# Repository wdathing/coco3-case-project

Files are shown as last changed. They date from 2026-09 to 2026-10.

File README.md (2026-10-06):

# CoCo3 Streamline Case

A parametric, 3D-printable replacement case for the Tandy Color Computer 3 (26-3334 motherboard), styled after
the never-released "CoCo4" prototype: a low keyboard deck in front of a taller louvered tower that houses the
motherboard and two 3.5" drive bays.

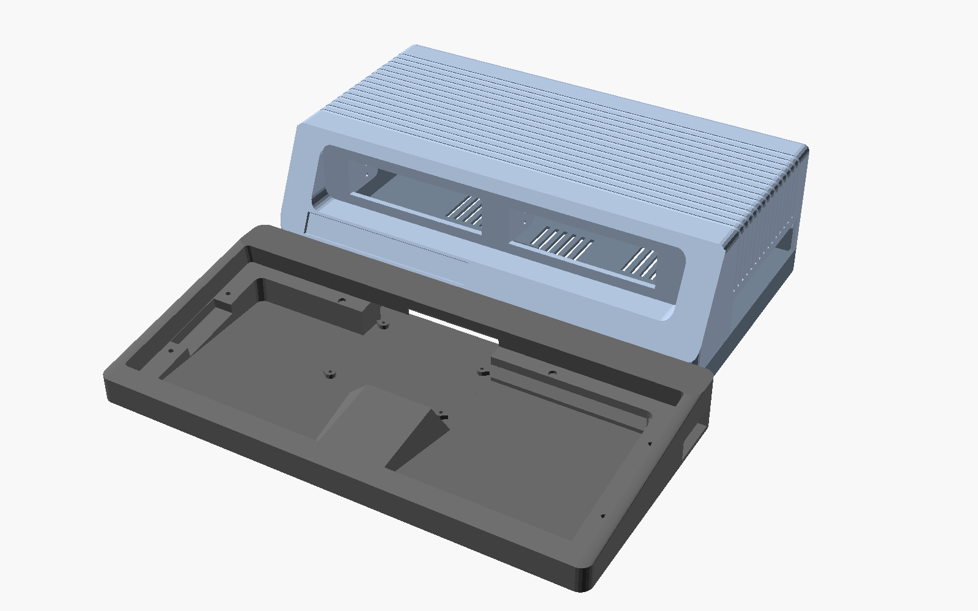
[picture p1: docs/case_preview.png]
The case: main tower and detachable keyboard shell


Everything is generated from OpenSCAD source ([`coco3_case.scad`](coco3_case.scad)). The motherboard outline,
mounting holes and connector positions come from a KiCad STEP model of the real board, so the rear ports and the
right-side cartridge slot line up with a stock CoCo3 board.

## Features

- **Fits a 250 x 250 mm bed.** The main case and keyboard shell are split into left/right halves, joined with M3
  screws, nuts and printed pins. "Whole" versions of each part are included for bigger printers.
- **Multipak-compatible cartridge slot.** The motherboard sits at the stock height above the desk, so a Multipak
  or a cartridge plugs into the right-side slot as it would on a stock case.
- **Keyboard shell** for either the original CoCo3 keyboard or an Artemis v3 replacement keyboard, each with its
  own bezel. The shell attaches with magnets (detachable) or bolts (permanent).
- **Two 3.5" drive bays** in the tower for floppy or Gotek drives, with filler plates for empty bays and a tray
  that holds a CoCo FujiNet board and its OLED display in a bay.
- **Modern I/O:** USB-C power input that replaces the OEM power connector, USB passthrough faceplates for a Pico-based
  USB keyboard controller, a rear panel for an HDMI/video add-on board, and mounting for a Raspberry Pi Zero
  (RGBtoHDMI) or an HDMI bulkhead coupler.
- **Build variants:**
  - **One-piece bottom.** The main bottom and keyboard shell print as a single part, for large printers
    (~334 x 341 mm footprint).
  - **Hinged lid.** The rear wall becomes part of the bottom and the top swings up on a 3 mm rod for access to the
    drives and motherboard.

## Which files to print

Ready-to-print STLs are in [`stl/`](stl) (the standard case) and [`hinged-stls/`](hinged-stls) (hinged-lid
versions of the main case parts). Pick one row from each group that applies:

| Part | Fits 250 mm bed (split) | Bigger printer (whole) |
|---|---|---|
| Main case bottom | `main_bottom_left` + `main_bottom_right` | `main_bottom_whole` |
| Main case top | `main_top_left` + `main_top_right` | `main_top_whole` |
| Keyboard shell | `keyboard_bottom_left` + `keyboard_bottom_right` + `keyboard_joiner_keys` | `keyboard_bottom_whole` |
| Keyboard bezel, stock keyboard | `bezel_oem_left` + `bezel_oem_right` | `bezel_oem_whole` |
| Keyboard bezel, Artemis v3 | `bezel_artemis_left` + `bezel_artemis_right` | `bezel_artemis_whole` |

Plus:

- `main_faceplate` and `keyboard_faceplate`: the USB/LED/button plates for the main case front and the keyboard's
  back wall.
- `keyboard_main_keys`: bow-tie keys that join the keyboard shell to the main bottom underneath.
- `keyboard_magnet_plugs` (detachable keyboard) **or** `keyboard_bridge_plate` (permanently attached keyboard).
- `usbc_clip`: holds the USB-C power board.
- Optional: `fujinet_tray`, `floppy_filler_plate` + 2x `floppy_filler_clip` (per empty bay).

**One-piece bottom (large printers):** print `bottom_one_piece` in place of the main bottom and keyboard shell
(and their keys/plugs), with `main_top_whole_1p` as the top. Its skirt is 5 mm taller to match.

**Hinged lid:** use the main case parts (`main_bottom_*`, `main_top_*`, `main_faceplate`, `bottom_one_piece`,
`main_top_whole_1p`) from `hinged-stls/`; everything else still comes from `stl/`.

## Hardware

- M3 screws throughout. By default they self-tap into 2.6 mm pilot holes; set `screw_mount_type = "heat_set"` for
  brass heat-set inserts (4.0 mm holes) instead.
- M3 x 10 (or x 12) socket-head screws and M3 nuts for the seams between split halves. Bolt the main case halves
  together *before* fitting the drives.
- 6 x 3 mm disc magnets for the detachable keyboard.
- 5 mm stick-on rubber feet.
- Hinged lid only: a 3 mm steel rod, about 306 mm long, glued at the ends.

## Building the STLs yourself

The STLs are generated from the `.scad` files by a build script. It needs an
[OpenSCAD development snapshot](https://openscad.org/downloads.html#snapshots) (2024 or later): the scripts use
the Manifold backend, which renders the whole set in seconds. The 2021.01 stable release doesn't have it.

```sh
./build_stls.sh                  # Linux / macOS: everything
./build_stls.sh hinged-stls      # just one folder
./build_stls.sh main_top_left    # just one part (in every folder that has it)
```

```bat
build_stls.cmd                   :: Windows, same arguments (or .\build_stls.ps1 from PowerShell)
```

The scripts find OpenSCAD on the `PATH` or in its default install location; set `OPENSCAD` to point at a specific
binary. The list of parts, with the settings each one is built with, is in [`stl_parts.txt`](stl_parts.txt).

## Customizing

Open `coco3_case.scad` in OpenSCAD and use the Customizer, or edit the variables at the top of the file. The most
useful ones:

| Variable | What it does |
|---|---|
| `part` | Which part to render. `"preview"` shows the case assembled; the full list is in the PART SELECTOR block at the end of the file. |
| `keyboard_attached` | `false` = detachable keyboard (magnets), `true` = bolted on. |
| `one_piece_bottom` | Fuse the main bottom and keyboard shell into one print. |
| `main_hinged` | Hinged-lid build. |
| `screw_mount_type` | `"self_tap"` or `"heat_set"`. |
| `new_foot_height` | Height of your stick-on feet. The standoffs adjust to keep the cartridge slot at Multipak height. |
| `tol` | General fit clearance. |

The floppy filler plate lives in its own file, [`coco3_floppy_filler.scad`](coco3_floppy_filler.scad).

## Status

This is a hobby project. Parts have been test-printed and fitted as the design evolved, but not every variant
has been printed. Check fit on your own printer before committing to a long print. A few dimensions are best
estimates, such as the height of the OEM rubber feet that the cartridge-height calculation starts from. They are
marked `PLACEHOLDER` / `TODO` in the source.

## Third-party files

These reference files are included for convenience and are **not** covered by this project's license. They
remain under their original owners' terms:

- `coco3.step`: CoCo3 motherboard model, from
  [qbancoffee/coco_motherboards](https://github.com/qbancoffee/coco_motherboards) (GPL-3.0).
- `coco4_reference.jpg`: photo of the CoCo4 prototype, used as the styling reference.
- `Artemis v3 bezel.stl`: bezel model for the Artemis v3 keyboard.
- `CoCo-FujiNet-Rev000.stl`: model of the CoCo FujiNet board.

## License

Copyright (c) 2026 Bill Athing.

Licensed under [Creative Commons Attribution 4.0 International (CC BY 4.0)](LICENSE). You can share, remix and
sell prints or derivatives, as long as you give credit, e.g. *"CoCo3 Streamline Case" by Bill Athing,
https://github.com/wdathing/coco3-case-project*, and note any changes you made.

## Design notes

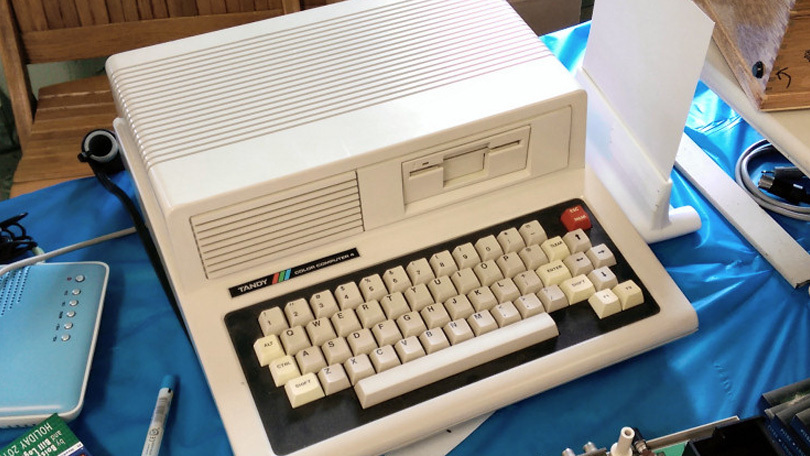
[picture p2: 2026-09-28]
coco4_reference.jpg

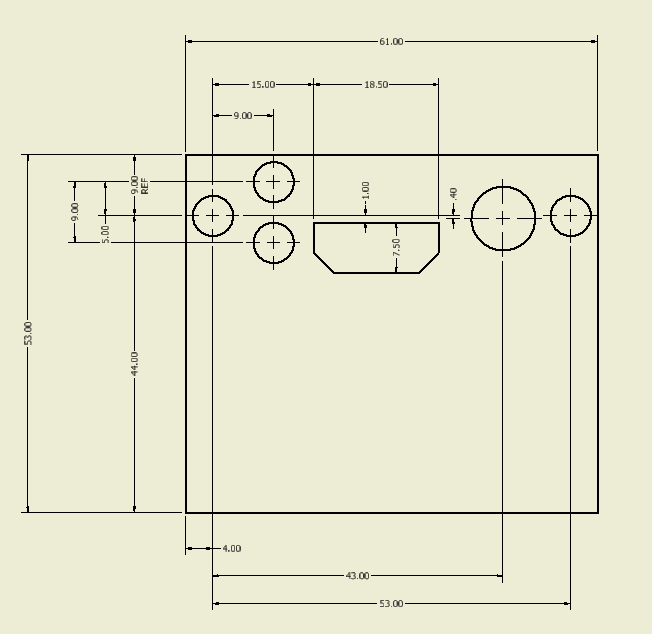
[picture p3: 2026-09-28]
coco-dv io template.png

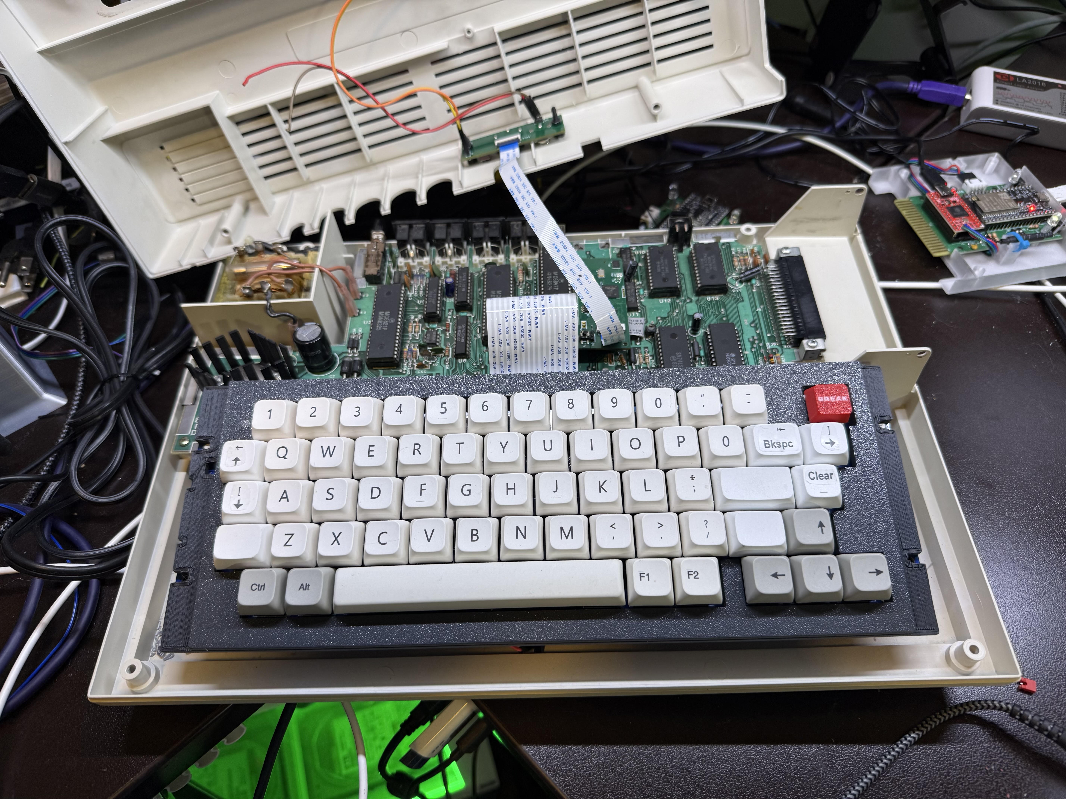
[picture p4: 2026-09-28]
coco2.jpg

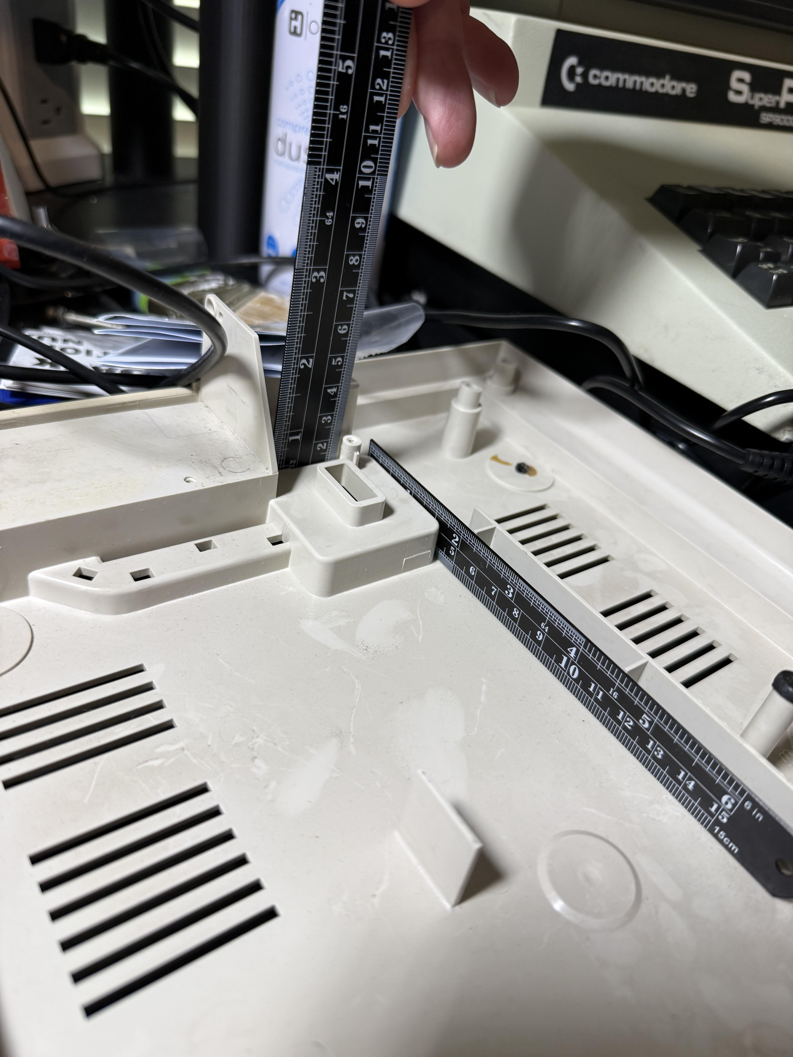
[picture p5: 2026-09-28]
coco3 rgb cn3 bump.jpg

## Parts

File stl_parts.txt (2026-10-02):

# Parts built by build_stls.sh / build_stls.ps1 -- one STL per line.
#
#   <output folder>  <output file name>  <.scad file>  <part>  [name=value OpenSCAD overrides...]
#
# <part> is the value of the file's `part` selector (see its PART SELECTOR block). Overrides are OpenSCAD
# expressions passed with -D, so they must not contain spaces. Lines starting with # are ignored.

# ---- stl/ : the default (v1.0) case -- two-piece main case, detachable keyboard ----
stl  main_bottom_left       coco3_case.scad  main_bottom_left
stl  main_bottom_right      coco3_case.scad  main_bottom_right
stl  main_bottom_whole      coco3_case.scad  main_bottom_whole
stl  main_top_left          coco3_case.scad  main_top_left
stl  main_top_right         coco3_case.scad  main_top_right
stl  main_top_whole         coco3_case.scad  main_top_whole
stl  main_faceplate         coco3_case.scad  main_faceplate
stl  keyboard_bottom_left   coco3_case.scad  keyboard_bottom_left
stl  keyboard_bottom_right  coco3_case.scad  keyboard_bottom_right
stl  keyboard_bottom_whole  coco3_case.scad  keyboard_bottom_whole
stl  keyboard_faceplate     coco3_case.scad  keyboard_faceplate
stl  keyboard_magnet_plugs  coco3_case.scad  keyboard_magnet_plugs
stl  keyboard_joiner_keys   coco3_case.scad  keyboard_joiner_keys
stl  keyboard_main_keys     coco3_case.scad  keyboard_main_keys
stl  keyboard_bridge_plate  coco3_case.scad  keyboard_bridge_plate
stl  bezel_oem_whole        coco3_case.scad  bezel_oem_whole
stl  bezel_oem_left         coco3_case.scad  bezel_oem_left
stl  bezel_oem_right        coco3_case.scad  bezel_oem_right
stl  bezel_artemis_whole    coco3_case.scad  bezel_artemis_whole
stl  bezel_artemis_left     coco3_case.scad  bezel_artemis_left
stl  bezel_artemis_right    coco3_case.scad  bezel_artemis_right
stl  usbc_clip              coco3_case.scad  usbc_clip
stl  fujinet_tray           coco3_case.scad  fujinet_tray
# one-piece bottom (big printers): its main top has a 5mm taller skirt, hence the _1p top
stl  bottom_one_piece       coco3_case.scad  bottom_one_piece  one_piece_bottom=true
stl  main_top_whole_1p      coco3_case.scad  main_top_whole    one_piece_bottom=true
stl  floppy_filler_plate    coco3_floppy_filler.scad  plate
stl  floppy_filler_clip     coco3_floppy_filler.scad  clip

# ---- hinged-stls/ : hinged-lid build -- back plate fused to the bottom, lid hinges at the rear ----
# Only the main case parts differ; everything else comes from stl/.
hinged-stls  main_bottom_left   coco3_case.scad  main_bottom_left   main_hinged=true
hinged-stls  main_bottom_right  coco3_case.scad  main_bottom_right  main_hinged=true
hinged-stls  main_bottom_whole  coco3_case.scad  main_bottom_whole  main_hinged=true
hinged-stls  main_top_left      coco3_case.scad  main_top_left      main_hinged=true
hinged-stls  main_top_right     coco3_case.scad  main_top_right     main_hinged=true
hinged-stls  main_top_whole     coco3_case.scad  main_top_whole     main_hinged=true
hinged-stls  main_faceplate     coco3_case.scad  main_faceplate     main_hinged=true
hinged-stls  bottom_one_piece   coco3_case.scad  bottom_one_piece   main_hinged=true  one_piece_bottom=true
hinged-stls  main_top_whole_1p  coco3_case.scad  main_top_whole     main_hinged=true  one_piece_bottom=true

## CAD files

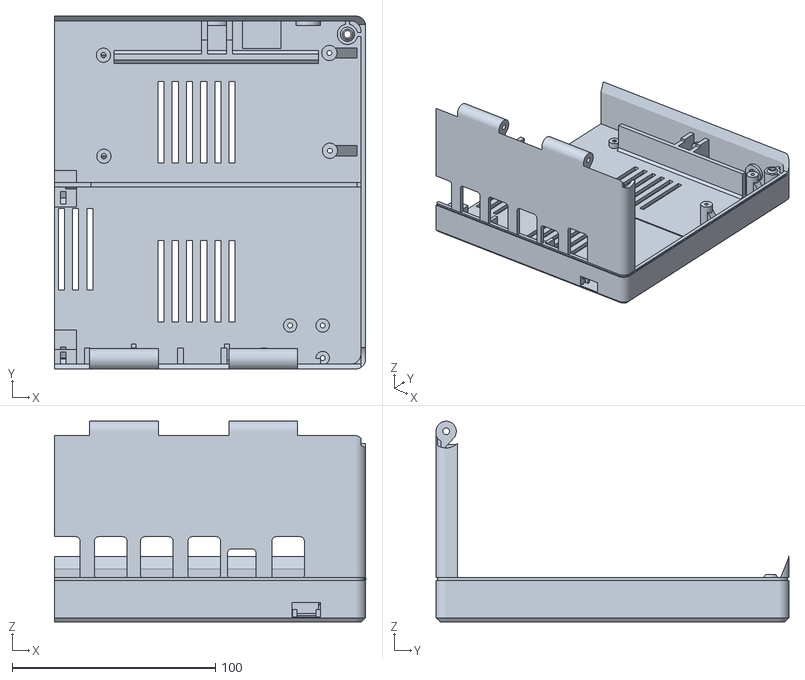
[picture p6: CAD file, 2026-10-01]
hinged-stls/main_bottom_right.stl
153.2 x 173.6 x 98.7

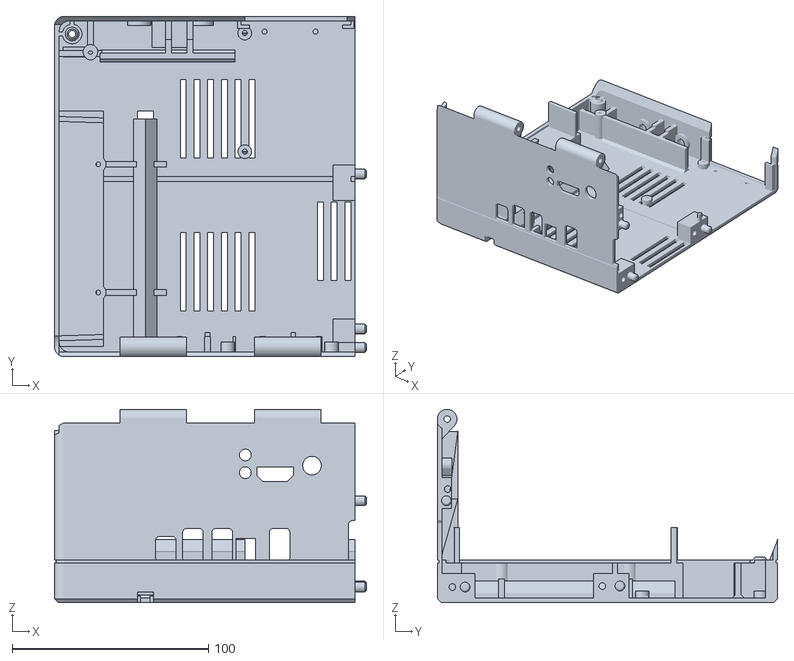
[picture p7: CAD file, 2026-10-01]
hinged-stls/main_bottom_left.stl
159.2 x 173.6 x 98.7

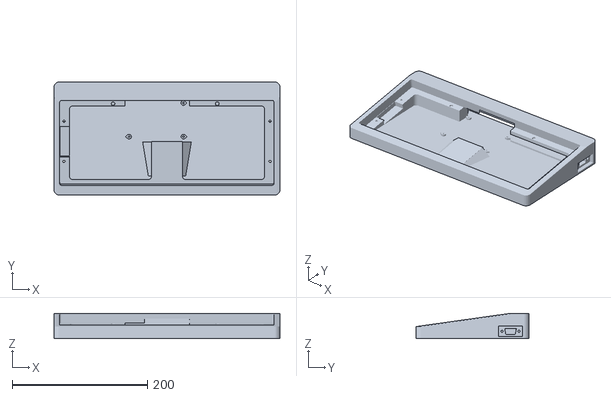
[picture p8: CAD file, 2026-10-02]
stl/keyboard_bottom_whole.stl
334.0 x 167.5 x 37.2

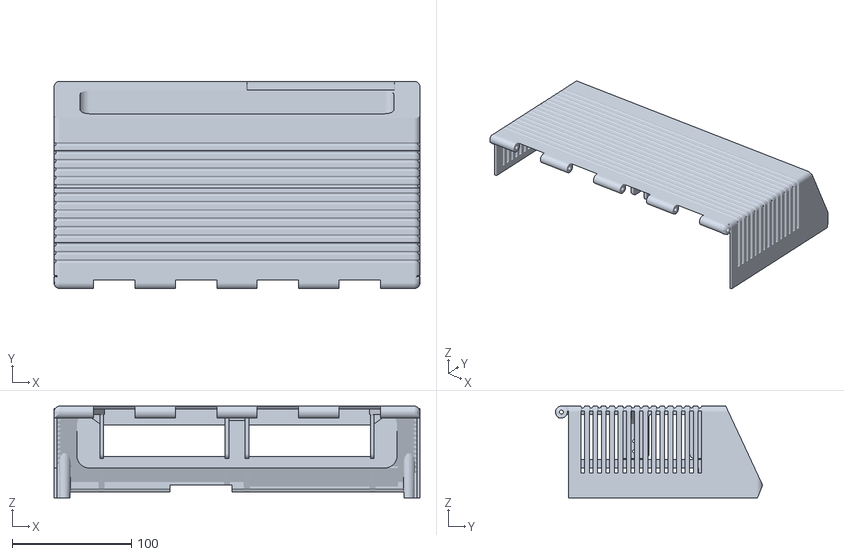
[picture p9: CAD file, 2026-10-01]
hinged-stls/main_top_whole.stl
306.3 x 173.4 x 76.8

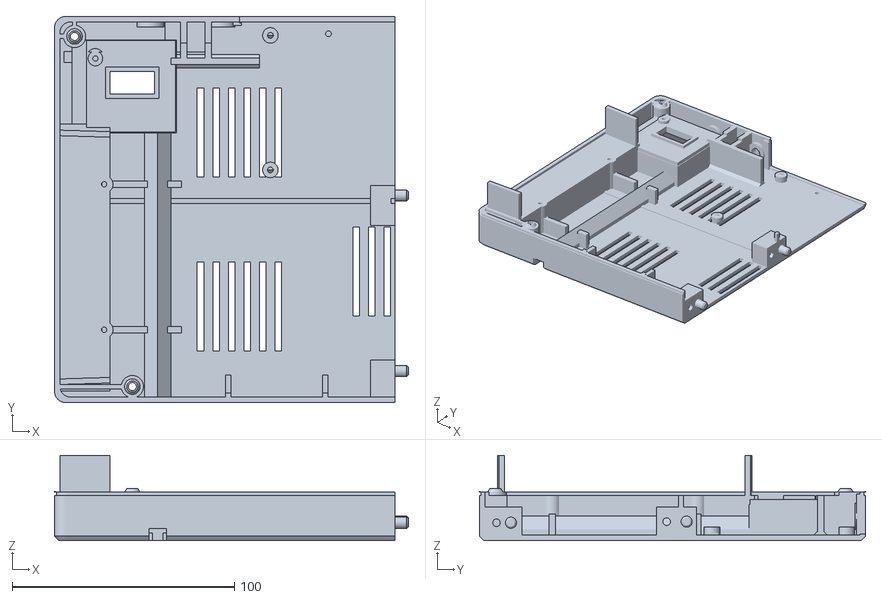
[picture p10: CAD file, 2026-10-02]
stl/main_bottom_left.stl
159.2 x 173.6 x 38.2

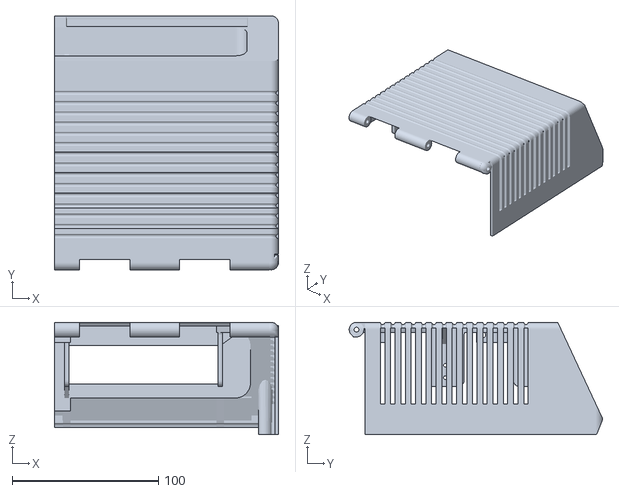
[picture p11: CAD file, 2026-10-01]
hinged-stls/main_top_right.stl
153.2 x 173.4 x 76.8

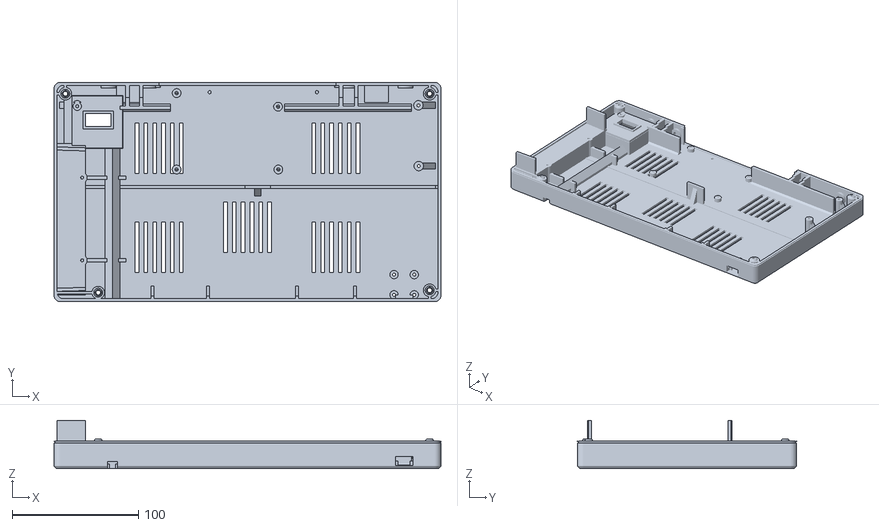
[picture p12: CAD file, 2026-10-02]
stl/main_bottom_whole.stl
306.3 x 173.6 x 38.2

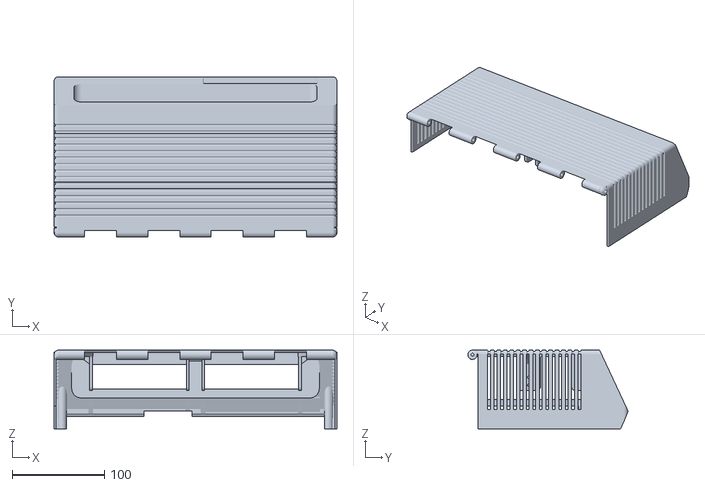
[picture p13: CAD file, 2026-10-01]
hinged-stls/main_top_whole_1p.stl
306.3 x 173.4 x 85.3

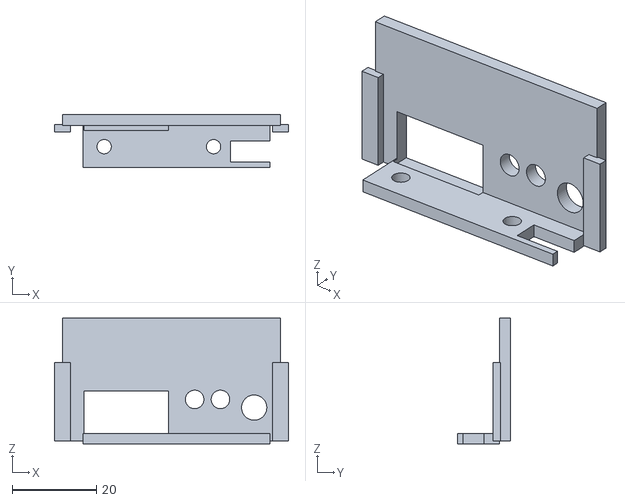
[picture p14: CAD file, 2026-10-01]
hinged-stls/main_faceplate.stl
55.6 x 12.7 x 29.8

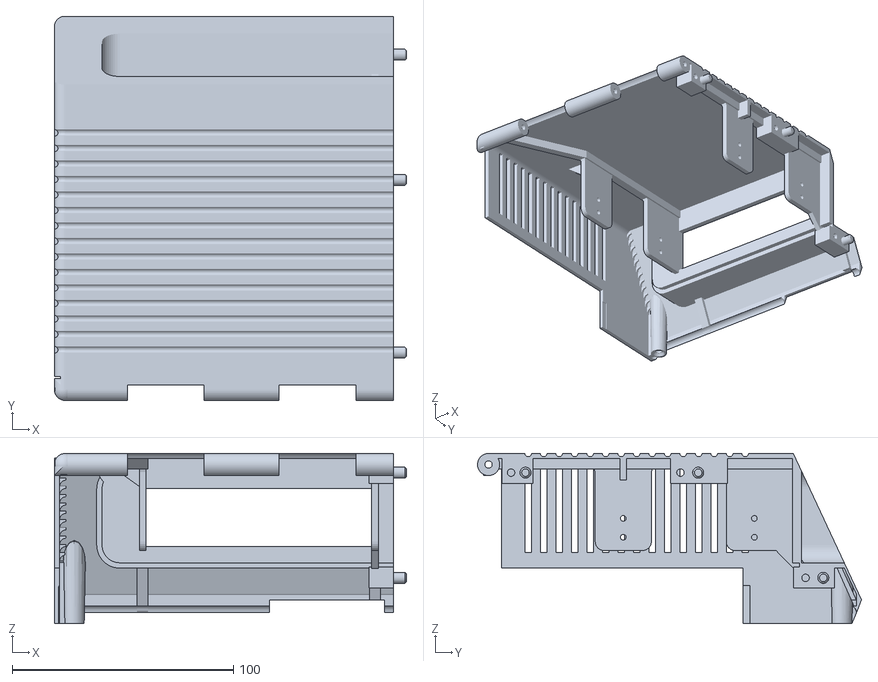
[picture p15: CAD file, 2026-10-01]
hinged-stls/main_top_left.stl
159.2 x 173.4 x 76.8

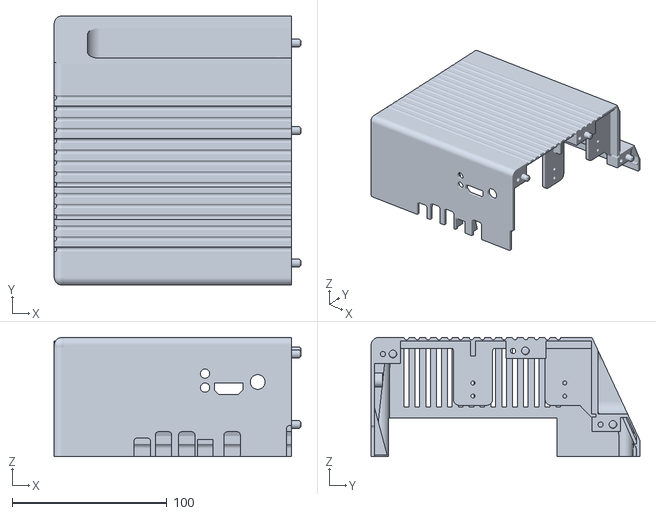
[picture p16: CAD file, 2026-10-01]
stl/main_top_left.stl
159.2 x 173.6 x 76.8

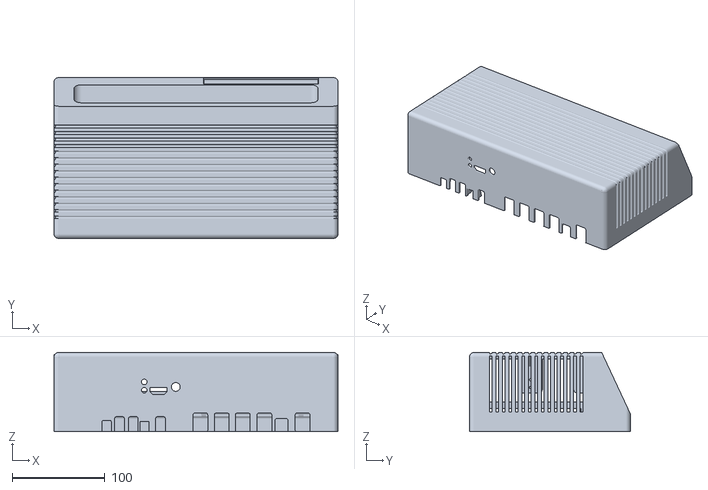
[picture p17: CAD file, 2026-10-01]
stl/main_top_whole_1p.stl
306.3 x 173.6 x 85.3

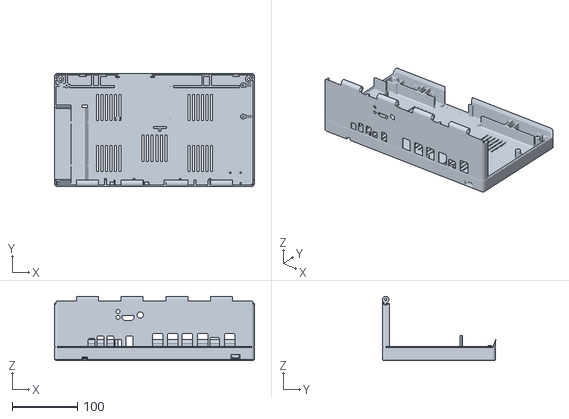
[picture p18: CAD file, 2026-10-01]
hinged-stls/main_bottom_whole.stl
306.3 x 173.6 x 98.7

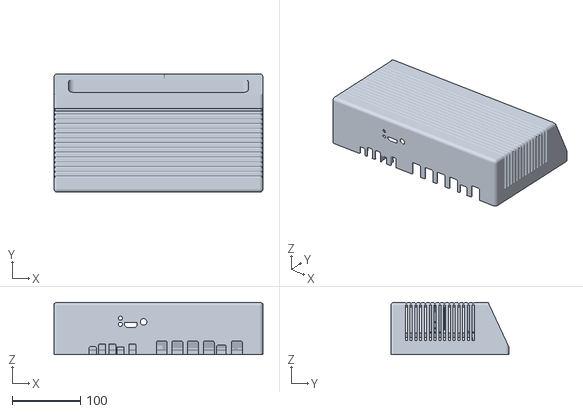
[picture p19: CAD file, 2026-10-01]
stl/main_top_whole.stl
306.3 x 173.6 x 76.8

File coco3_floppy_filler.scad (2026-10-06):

// SPDX-License-Identifier: CC-BY-4.0
// Copyright (c) 2026 Bill Athing -- https://github.com/wdathing/coco3-case-project
// ============================================================================
// FLOPPY BAY FILLER PLATE -- separate file (per direction: "I wonder if this
// should maybe be in a separate file too") -- covers one empty 3.5" bay
// opening in the floppy bulkhead when no drive is installed there.
//
// Prints FLAT, decorative face up: no supports, best surface finish on the
// visible face, easy to add color (filament-swap bands or paint) per
// direction ("it should print flat... face up to have nice detail and
// perhaps colors added"). The back face (down, on the bed) carries two
// shallow pockets for a separate spring-clip part (also in this file) that
// friction/spring-fits into the bulkhead opening to retain the plate --
// "spring clips ... printed separate and insert, perhaps with glue, into
// slots in the back."
//
// Decorative treatment: a recessed center panel with half-round horizontal
// "louver" grooves, using the same "cylinder axis sits exactly on the
// surface, cutting only the inward half" technique as the main case's own
// decorative grooves -- kept visually consistent with the rest of the case.
//
// NOTE: dimensions below are copied from coco3_case.scad's own floppy_* /
// wall constants rather than `use`d/`include`d -- `include` would also
// execute that file's own part-selector at the bottom and mix its current
// default part into this file's output. Keep these in sync by hand if the
// bulkhead opening changes in the main file.
//
// FIRST PASS: the clip's spring geometry (arm_len/arm_w/t below) has not
// been print-fit-tested. Expect to retune after the first print.
// ============================================================================

$fn = 64;

// --- copied from coco3_case.scad (see note above) ---
// Bulkhead opening tightened after a real print test ("opening is about
// 3mm too wide and 2mm too tall") -- floppy_fit_clear_w/h there replace
// the old single floppy_fit_clear=3 this file used to mirror.
floppy_w           = 101.6;
floppy_h           = 25.4;
floppy_fit_clear_w = 0.3;
floppy_fit_clear_h = 1.3;

opening_w = floppy_w + floppy_fit_clear_w;   // 101.9 -- matches the real bulkhead opening
opening_h = floppy_h + floppy_fit_clear_h;   // 26.7

// --- filler plate parameters ---
flange_margin  = 3;      // flange overlap past the opening, all sides -- keeps it from falling through
flange_t       = 3.5;    // overall plate thickness
inset_depth    = 1;      // decorative panel recess depth
inset_margin   = 6;      // solid border width kept around the decorative panel
corner_r       = 4;      // plate's own outer corner rounding
inset_corner_r = 2.5;    // recessed panel's corner rounding

flange_w = opening_w + 2*flange_margin;   // 110.6
flange_h = opening_h + 2*flange_margin;   // 34.4

groove_r     = 1.0;      // shallower than the main case's 1.5mm -- there's less material to spare here
groove_n     = 4;        // a fixed count, centred on the panel (per direction -- the fixed-pitch loop lost one
                          // when the opening shrank and the panel got shorter)
groove_pitch = 5;        // at most; tightened if the panel can't fit groove_n at this pitch
groove_edge_clear = 3;   // keep grooves this far from the panel's own top/bottom edge

// --- spring clips ---
// Mechanism (2026-09-30 rework, per a print fit): each clip is a lofted blade standing ON EDGE in a blind pocket in
// the plate's back (foot anchored, glue if needed), one per side, centred vertically in a 20mm-tall slot. One face of
// the blade (local Z=0, matched to the pocket's own reference face) stays flat; the other carries the profile: base
// thickness through the foot, a thin waist that does the flexing, then a ROUNDED BUMP. The pocket leans outward so the
// relaxed bump reaches clip_bump_preload past the opening's side edge; installed, the bump presses on the bulkhead's
// opening side and the drive rail right behind it (the rails are flush with the opening's side edges, so there is no
// ledge behind the bulkhead to hook -- the old barb-and-catch clip ran into the rail). Holds by spring pressure; both
// sides of the bump are gentle ramps, so it pushes in and pulls out. The rest of the blade stays clear of the wall.
// Also fixed: the slots used to sit at a fixed X = 52 from when the opening was 104.6 wide -- outside today's 101.9
// opening. The position is derived from opening_w now.
clip_base_t   = 1.1;     // blade thickness through the foot (was 0.9)
clip_hinge_t  = 0.45;    // thickness at the flex waist -- concentrates the bend there (was 0.35)
clip_bump_t   = 1.8;     // bump crest thickness
clip_tip_t    = 0.6;     // thickness at the tip (lead-in)
clip_slot_h   = 20;      // the slot in the plate's back, along the plate's vertical
clip_blade_w  = clip_slot_h - 0.3;    // blade width at the base -- the plate's local Y (vertical) once installed
clip_tip_w    = clip_blade_w - 4;     // blade width at the tip (lead-in)
clip_arm_w    = clip_blade_w - 1;     // width through the waist/bump region
clip_foot_len = 2.0;     // portion anchored in the plate's blind pocket
clip_arm_len  = 8.0;     // portion projecting free past the back face, into the bay opening
clip_total_len = clip_foot_len + clip_arm_len;
clip_face_clr  = 0.3;    // blade's outer face this far inside the opening's edge at the bay face
clip_bump_preload = 0.8; // bump crest this far past the opening's edge at rest = how much it presses when installed
clip_pocket_d  = clip_foot_len + 0.5;   // blind pocket depth into the plate's back
clip_bump_pos  = [clip_foot_len + 5.0, clip_foot_len + 5.6];   // bump crest (start, end) along the clip, from the foot's deep end
clip_bump_depth = (clip_bump_pos[0] + clip_bump_pos[1])/2 - clip_pocket_d;   // crest's distance behind the plate's back face
clip_x_offset  = opening_w/2 - clip_face_clr - clip_base_t;   // pocket's reference (inner) face, at the back face
// Lean outward so the crest lands clip_bump_preload past the edge: offset + depth*tan(splay) + bump_t = edge + preload.
clip_splay_deg = atan((clip_face_clr + clip_base_t + clip_bump_preload - clip_bump_t) / clip_bump_depth);
clip_y_offset  = 0;      // centred vertically

module rounded_rect_2d(w, h, r) {
    offset(r = r) offset(delta = -r) square([w, h], center = true);
}

module floppy_filler_clip_pocket() {
    // Blind pocket for one clip's foot, angled outward by clip_splay_deg.
    // Only the foot depth is cut here -- the arm projects into open space
    // beyond the back face and isn't part of the plate's own geometry.
    // Matches the clip's own foot cross-section (local Z 0..clip_base_t,
    // Y -clip_blade_w/2..clip_blade_w/2) with a little clearance -- not
    // centered in X, so the pocket's local X=0 face lines up with the
    // blade's flat (non-bump) reference face. Clearance tightened from
    // 0.3 to 0.15 after the wider gap printed loose.
    pocket_w = clip_base_t + 0.15;
    pocket_h = clip_slot_h;
    pocket_d = clip_pocket_d;
    rotate([0, -clip_splay_deg, 0])
        translate([-0.15, -pocket_h/2, 0])
            cube([pocket_w, pocket_h, pocket_d]);
}

module floppy_filler_clip_pockets() {
    for (side = [-1, 1])
        for (yo = [clip_y_offset])                 // one per side now
            translate([side*clip_x_offset, yo, 0])
                mirror([side < 0 ? 1 : 0, 0, 0])
                    floppy_filler_clip_pocket();
}

module floppy_filler_plate() {
    panel_w = flange_w - 2*inset_margin;
    panel_h = flange_h - 2*inset_margin;
    difference() {
        linear_extrude(height = flange_t)
            rounded_rect_2d(flange_w, flange_h, corner_r);

        // recessed decorative panel (cut down from the top/decorative face)
        translate([0, 0, flange_t - inset_depth])
            linear_extrude(height = inset_depth + 0.1)
                rounded_rect_2d(panel_w, panel_h, inset_corner_r);

        // half-round louver grooves within the panel -- cylinder axis sits
        // exactly on the recessed panel's own surface, so only the inward
        // half is ever removed
        let (pitch = min(groove_pitch, (panel_h - 2*groove_edge_clear) / (groove_n - 1)))
        for (i = [0 : groove_n - 1])
            let (gy = (i - (groove_n - 1)/2) * pitch)
            translate([0, gy, flange_t - inset_depth])
                rotate([0, 90, 0])
                    cylinder(r = groove_r, h = panel_w + 0.2, center = true);

        // blind pockets for the two spring clips (see floppy_filler_clip_pocket)
        floppy_filler_clip_pockets();
    }
}
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

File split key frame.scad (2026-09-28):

$fn = 50;

box_width = 334;
box_depth = 155;
front_height = 14.7;
slope_angle = 15;
wall_thickness = 3;
corner_radius = 8;
grill_enabled = true;

left_right_support = 30;
front_back_support = 20;

pcb_width = 316;
pcb_depth = 124;
pcb_recess = 12;

pin_sd = 5;
pin_wd = 7;
pin_tol = 0.12;


base_plate_thickness = 2 + 2 + 1;

rear_height = front_height + tan(slope_angle) * (box_depth-2*corner_radius);

keyb_pcb_left_edge = (box_width - pcb_width) / 2;
keyb_pcb_right_edge = keyb_pcb_left_edge + pcb_width;

module grill(g_x, g_y, width, slots)
{
    grill_slot_width = 30;
    grill_slot_height = 30;
    grill_slot_spacing = 20;
    grill_z = -60;
    grill_x_start = 10;

    // grill slots with rounded ends
    spacing = grill_slot_width + grill_slot_spacing ;
    for (y = [g_y : spacing : g_y + spacing * slots]) 
    {
        // vertical slot body
        hull()
        {
        //translate([g_x+grill_slot_width/5, y, grill_z])
        //rotate([-slope_angle, 0, 0])
        //cube([width, grill_slot_width, 400]);

        // rounded ends (top and bottom)
        translate([g_x, y+grill_slot_width/2, grill_z])
            rotate([-slope_angle, 00, 0])
                cylinder(h = 100, d = grill_slot_width);

        translate([g_x + width,  y+grill_slot_width / 2, grill_z])
            rotate([-slope_angle, 0, 0])
                cylinder(h = 100, d = grill_slot_width);
        }
    }
}

module hollow_int(offset_hollow_x=0)
{
    translate([offset_hollow_x,0,0])
    translate([left_right_support, front_back_support, base_plate_thickness])
        hull() {
            // front left corner
            translate([corner_radius - 10, corner_radius, 0])
                cylinder(h = rear_height, r = corner_radius - wall_thickness);
            // front right
            translate([box_width/2 - 2 * left_right_support - corner_radius+10, corner_radius, 0])
                cylinder(h = rear_height, r = corner_radius - wall_thickness);
            translate([corner_radius - 10, box_depth - front_back_support - corner_radius - 20, 0])
                cylinder(h = rear_height, r = corner_radius - wall_thickness);
            translate([box_width/2 - 2 * left_right_support - corner_radius + 10, box_depth - front_back_support - corner_radius - 20, 0])
                cylinder(h = rear_height, r = corner_radius - wall_thickness);
        }
}

// original full box module
module full_shell(cut_left=true, pins_and_holes=false) {
    slide_back = 4;
    rotate([-slope_angle, 0, 0])
    difference() {
        // Outer shell
        hull() {
            translate([corner_radius, corner_radius, 0])
                cylinder(h = front_height, r = corner_radius);
            translate([box_width - corner_radius, corner_radius, 0])
                cylinder(h = front_height, r = corner_radius);
            translate([corner_radius, box_depth - corner_radius, 0])
                cylinder(h = rear_height, r = corner_radius);
            translate([box_width - corner_radius, box_depth - corner_radius, 0])
                cylinder(h = rear_height, r = corner_radius);
        }

        // Hollow interior
        hollow_int();
        hollow_int(box_width/2);
        
        // PCB recess
        //if (0)
        rotate([slope_angle, 0, 0])
        translate([
            keyb_pcb_left_edge,
            (box_depth - pcb_depth ) / 2+slide_back,
            0 //rear_height - pcb_recess - 34
        ])
            cube([pcb_width, pcb_depth, rear_height]);
        
        // underside metal lip on stock keyb
        translate([
            keyb_pcb_left_edge,
            (box_depth - pcb_depth ) / 2 + slide_back+4.5,
            //rear_height - pcb_recess - 6
            6
        ])
            rotate([slope_angle, 0, 0])
            {
                //cube([pcb_width, 3, 100]);
                rotate([0,90,0])
                    cylinder(h=pcb_width, d=4);
                rotate([0,90,0])
                translate([0,114.5,0])
                    //cube([pcb_width, 3, 100]);
                    
                    cylinder(h=pcb_width, d=4);
            }
        
        
        // make room for ribbon cable off keyboard
        {
            ribbon_w = 66;
            ribbon_vert = 18;
            ribbon_x = (box_width - ribbon_w) / 2;
            ribbon_y = box_depth - wall_thickness - 0.1 - 16;
            ribbon_z = rear_height - 24;
            translate([ribbon_x, box_depth-71-3, ribbon_z-1.6])
                cube([ribbon_w, 70.8, ribbon_vert]);  
            translate([ribbon_x, box_depth-70.8-1, ribbon_z-1.6-12])
                cube([ribbon_w, 70.8-8, ribbon_vert]);  

        }

        // USB passthrough (right half only)
        //if (!cut_left) 
        {
            usb_w = 66;
            usb_h = 20;
            usb_vert = 13;
            usb_x = (box_width - usb_w) / 2;
            usb_y = box_depth - wall_thickness - 0.1 - 15;
            usb_z = base_plate_thickness-1*1.6;

            // back panel cutout
            translate([usb_x, box_depth-70.8-1, usb_z-1.6])
                cube([usb_w, 68, 15]);  
            
            // recess for controller pcb... brought in a bit to make a lip
            translate([usb_x, usb_y-10, usb_z])
                cube([usb_w, 50, usb_vert]); 
        }

        // cutouts in the angled PCB plane
        //rotate([slope_angle, 0, 0])
        {
            // rear_height = front_height + tan(slope_angle) * box_depth;
            promicro_x = 16;
            // promicro_y = (box_depth - 45)/2-3;
            promicro_y = (box_depth - 45)/2-3;
            promicro_z = 6;// + tan(slope_angle) * 15;
            promicro_w = 24;
            promicro_d = 50;
            promicro_height = 20;
            
            // Clearance cutout on left interior support wall
            translate([promicro_x-7, promicro_y+slide_back+1, promicro_z-1])  // centered vertically on the left side
                rotate([slope_angle, 0, 0])
                    cube([promicro_w, promicro_d-5, promicro_height-2]);  // 25mm wide (x), 45mm deep (y), 15mm tall (z)

            if (0)
            // piano switch cutout
            translate([0, promicro_y+2+slide_back, promicro_z])  // centered vertically on the left side
                rotate([slope_angle, 0, 0])
                    cube([promicro_w, promicro_d-6, 10]);  // 25mm wide (x), 45mm deep (y), 15mm tall (z)

            
            
            // Clearance cutout on left interior support wall  smaller higher shelf
//            translate([promicro_x-7, promicro_y+slide_back, promicro_z+8.5])  // centered vertically on the left side
//                rotate([slope_angle, 0, 0])
//                    cube([promicro_w, promicro_d-6, 5]);  // 25mm wide (x), 45mm deep (y), 15mm tall (z)

            // Clearance cutout on right washers
            
            // front
            translate([keyb_pcb_right_edge-6.5, promicro_y-7+slide_back, promicro_z+2])  // centered vertically on the left side
                rotate([slope_angle, 0, 0])
                    cylinder(d=12, h=20);  // 25mm wide (x), 45mm deep (y), 15mm tall (z)
            
            // back
            translate([keyb_pcb_right_edge-6.5, promicro_y+promicro_d+slide_back, promicro_z+promicro_height-3
            ])  // centered vertically on the left side
                rotate([slope_angle, 0, 0])
                    cylinder(d=12, h=20);  // 25mm wide (x), 45mm deep (y), 15mm tall (z)


            // left side
            
            // Clearance cutout on left washers
            
            // front
            translate([promicro_x-0.5, promicro_y-7+slide_back, promicro_z+2])  // centered vertically on the left side
                rotate([slope_angle, 0, 0])
                    cylinder(d=11, h=20);  // 25mm wide (x), 45mm deep (y), 15mm tall (z)
            
            // back
            translate([promicro_x-0.5, promicro_y+promicro_d+slide_back+1, promicro_z+promicro_height-3
            ])  // centered vertically on the left side
                rotate([slope_angle, 0, 0])
                    cylinder(d=12, h=20);  // 25mm wide (x), 45mm deep (y), 15mm tall (z)            
        }


        
        // Cut the unwanted half
        if (cut_left) {
            
            //translate([box_width / 2 - 0, box_depth -11 + pin_tol, 0])
            // hole for pin
            if (pins_and_holes)
            translate([box_width / 2, box_depth - 8, 20])
                rotate([0,-90,0])
                    cylinder(h=25+pin_tol,d1=pin_wd+pin_tol, d2=pin_sd+pin_tol);            
            
            // Remove right half
            translate([box_width / 2, -10, -50])
                cube([box_width, box_depth + 20, rear_height + 100]);
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

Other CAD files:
stl/main_top_right.stl
stl/bezel_artemis_whole.stl
stl/bezel_oem_whole.stl
stl/keyboard_main_keys.stl
coco3_case.scad
Artemis v3 bezel.stl
CoCo-FujiNet-Rev000.stl
Coco_pico_keyb.step
Coco_pico_keyb.stl
hinged-stls/bottom_one_piece.stl
split key frame.stl
stl/bezel_artemis_left.stl
stl/bezel_artemis_right.stl
stl/bezel_oem_left.stl
stl/bezel_oem_right.stl
stl/bottom_one_piece.3mf
stl/bottom_one_piece.stl
stl/floppy_filler_clip.stl
stl/floppy_filler_plate.3mf
stl/floppy_filler_plate.stl
stl/fujinet_tray.stl
stl/keyboard_bottom_left.stl
stl/keyboard_bottom_right.stl
stl/keyboard_bridge_plate.stl
stl/keyboard_faceplate.stl
stl/keyboard_joiner_keys.stl
stl/keyboard_magnet_plugs.stl
stl/main_bottom_right.stl
stl/main_faceplate.stl
stl/usbc_clip.stl

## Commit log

2026-09-28 CoCo3 Streamline Case 1.0
    Parametric OpenSCAD case for the Tandy Color Computer 3 (26-3334), styled
    after the CoCo4 prototype: low keyboard section, louvered rear tower with
    twin 3.5" drive bays.
    - Main bottom/top shells built from the real motherboard outline, standoff
    and connector data (coco3.step); Multipak-compatible cartridge height.
    - Split halves for 250mm printers (M3 screw + nut seam lugs with pins), or
    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
    [Artemis v3 bezel.stl, Coco_pico_keyb.step, Coco_pico_keyb.stl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]
2026-09-30 Hinged lid mode, FujiNet bay tray, USB-C clip, split-top braces
    - main_hinged: the top's rear wall (with corner returns, DV I/O bosses and
    plate fins) becomes a back plate fused to the bottom; the rest is a lid
    hinged on the rounded rear-top edge (9 knuckles, 3mm rod). Front seam is
    an arc about the hinge axis so the lid clears a docked keyboard; swing
    checked clear 3..130 deg. Plate seam lug for split bottoms. Exports in
    hinged-stls/.
    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
    [CoCo-FujiNet-Rev000.stl, bottom_one_piece.stl, coco3_case.scad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]
2026-09-30 Floppy filler: clips fit the corrected opening, side spring clips, 4 grooves
    - Clip slots were still at a fixed X from the old 104.6mm opening, outside
    today's 101.9mm one; their position is now derived from the opening.
    - One 20mm-wide spring clip per side (was two small ones per side), a bit
    thicker, with a rounded bump that presses 0.8mm on the opening side and
    the drive rail -- the rails sit flush behind the bulkhead, so there is no
    ledge for a hooking barb. New "assembly" part shows the clips seated.
    - Face grooves are a fixed count of 4 again (the fixed-pitch loop dropped
    one when the panel got shorter).
    [coco3_floppy_filler.scad, floppy_filler_clip.stl, floppy_filler_plate.stl]
2026-10-01 Angled spine ribs, hinged lid corner cleanup, braced hinged faceplate
    - All tops: outer spine ribs angle from the rear drive bracket to the
    middle of the corner hinge knuckle (rear wall on non-hinged tops).
    - Hinged lids: clear the leftover corner-rounding slivers that hung off
    both back corners under the hinge (was one-piece only).
    - Hinged main faceplate: the thin band over the window is gone from the
    base and the lid (incl. the lid's skirt fillet); the plate grows to
    fill it, flat-topped 0.3 under the lid. Side tabs ride in channels on
    the inside of the wall (replace the stop blocks). Plate and window
    narrowed to the openings (X 84..136, screws at 94/120); attached-
    keyboard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
    [bottom_one_piece.stl, coco3_case.scad, main_bottom_left.stl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]
2026-10-02 Add slicer project files for one-piece bottom and floppy filler plate
    [bottom_one_piece.3mf, floppy_filler_plate.3mf]
2026-10-02 Add STL build scripts, README, CC BY 4.0 license
    - build_stls.sh (Linux/macOS) and build_stls.ps1 / build_stls.cmd (Windows)
    rebuild stl/ and hinged-stls/ from the parts list in stl_parts.txt using an
    OpenSCAD nightly (Manifold backend).
    - README with features, print guide, hardware, build and customizing notes.
    - LICENSE: CC BY 4.0, copyright Bill Athing; SPDX headers on the .scad files.
    Third-party reference files keep their own terms.
    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
    [coco3_case.scad, coco3_floppy_filler.scad, keyboard_bottom_left.stl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]
2026-10-06 Point links at the new repo name (coco3-case-project)
    [coco3_case.scad, coco3_floppy_filler.scad]
